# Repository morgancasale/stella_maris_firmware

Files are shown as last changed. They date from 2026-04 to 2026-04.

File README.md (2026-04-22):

# Rehabilitation Devices for One-Handed Interaction

<p align="center">
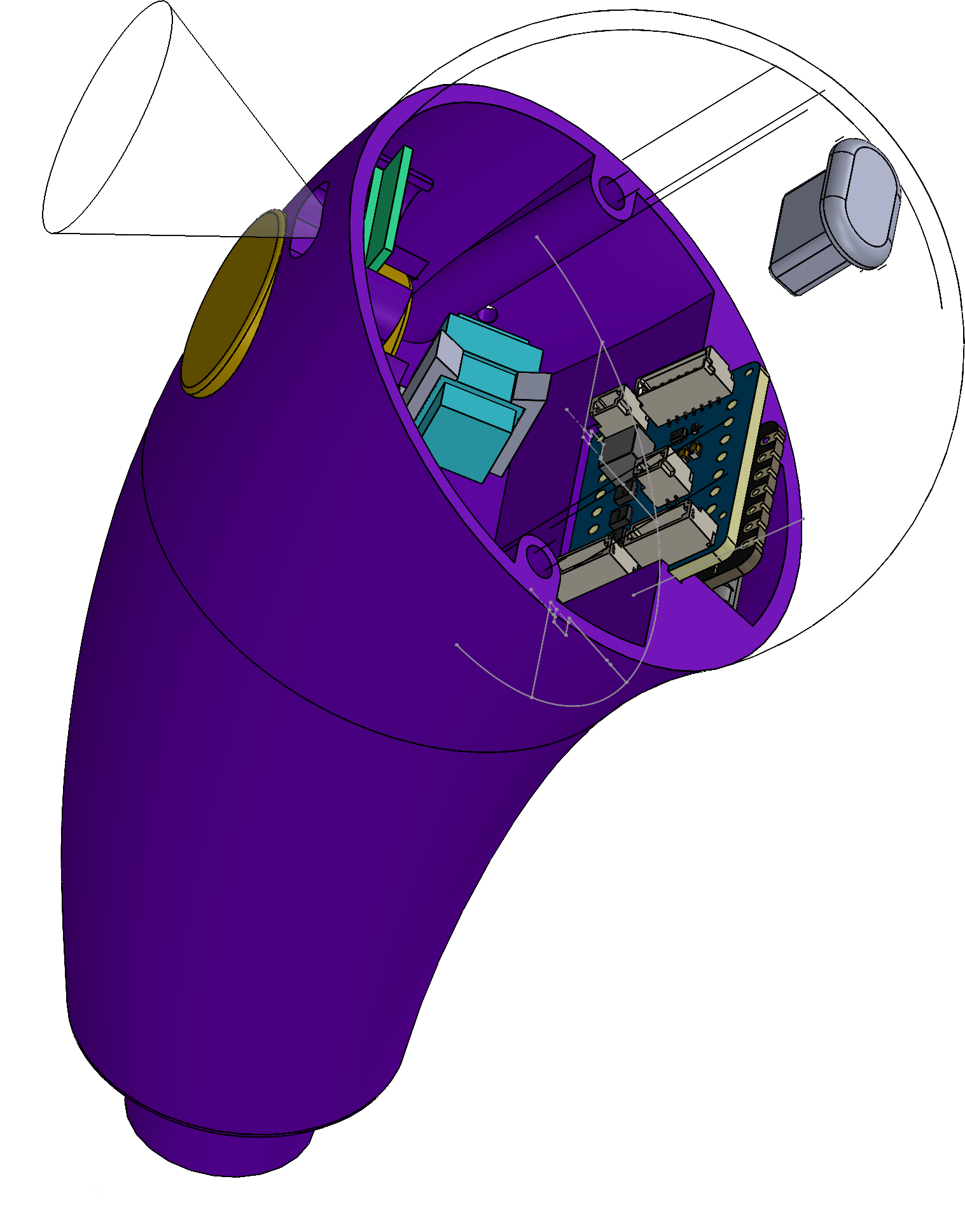
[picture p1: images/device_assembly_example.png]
     
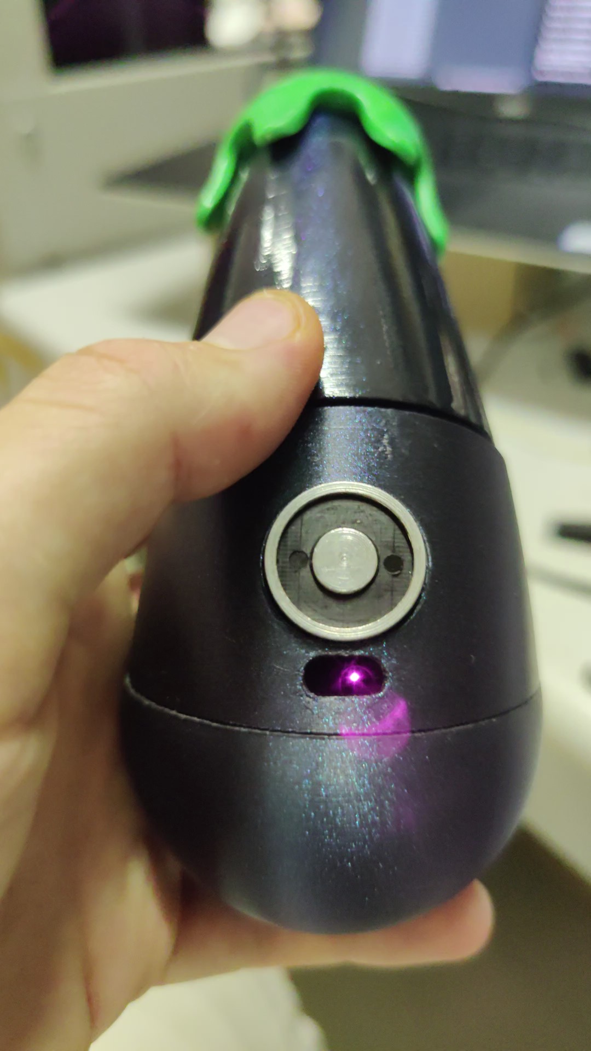
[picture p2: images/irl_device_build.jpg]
    
</p>

This project focuses on the design and development of compact rehabilitation devices intended for children who cannot use one hand. The goal is to provide engaging physical objects that help stimulate motor activity and interaction during therapy exercises.

The devices integrate sensing, actuation, and wireless communication in a very compact form factor.

---

## Project Overview

Each device contains:

- **Electromagnets** used for actuation and interaction with the patients  
- **Time-of-Flight (ToF) sensors** to detect the distance from patients  
- A **Seeed Studio XIAO ESP32-C6** microcontroller for control and wireless communication  

The devices communicate wirelessly and interact with a browser-based interface, allowing therapists or developers to monitor and control the system.

---

## Features

- Embedded firmware for **ESP32-C6**
- **Bluetooth Low Energy (BLE)** interface for communication with a JavaScript web application
- **ESP-NOW mesh-style communication** enabling multiple devices to exchange data with each other
- Integration of multiple sensors and electromagnets in a constrained physical space
- Designed for **low-power embedded operation**

---

## System Architecture

The system consists of three main layers.

### Embedded Device

Each device runs firmware on the **XIAO ESP32-C6** that:

- Reads data from ToF sensors  
- Controls electromagnets  
- Communicates with other devices using ESP-NOW  
- Exposes BLE services for external control  

### Device-to-Device Communication

Devices use **ESP-NOW** to exchange messages, enabling cooperative behaviors between multiple rehabilitation objects without requiring a central router.

### Web Interface

A **JavaScript-based interface** connects to the devices through **Bluetooth Low Energy (BLE)** to:

- Monitor device status  
- Send control commands  
- Configure behaviors  

---

## Hardware

Main components:

- **XIAO ESP32-C6**
- **Time-of-Flight (ToF) distance sensors**
- **Electromagnets**
- Custom compact enclosure designed to fit all components

The design focuses on integrating all components into a very small footprint suitable for small handheld objects.

---

## PCB Design

<p align="center">
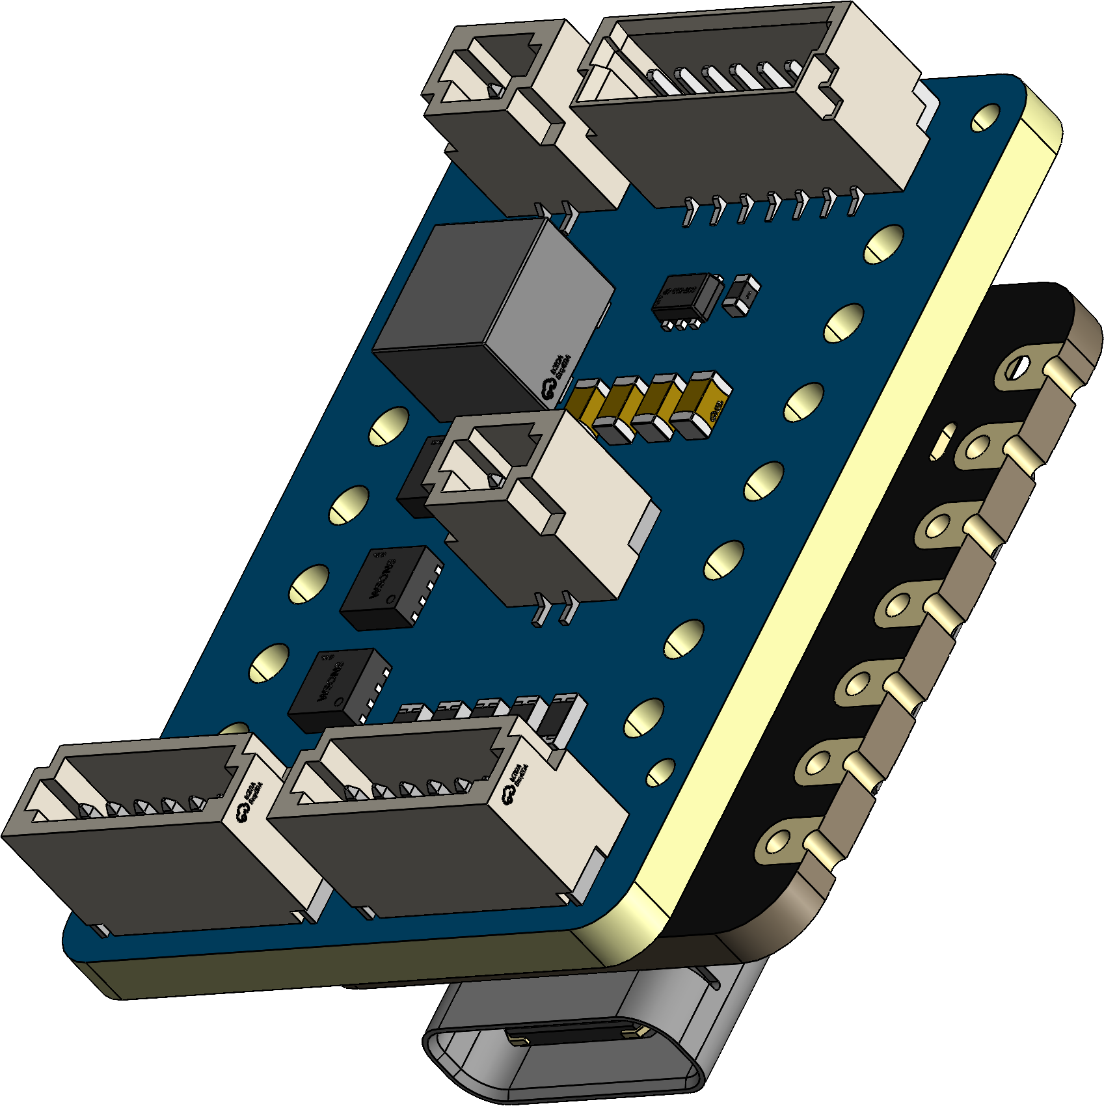
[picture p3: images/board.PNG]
    
</p> 

A custom PCB was designed to integrate all the electronic components into a compact form factor suitable for the rehabilitation devices.

<p align="center">
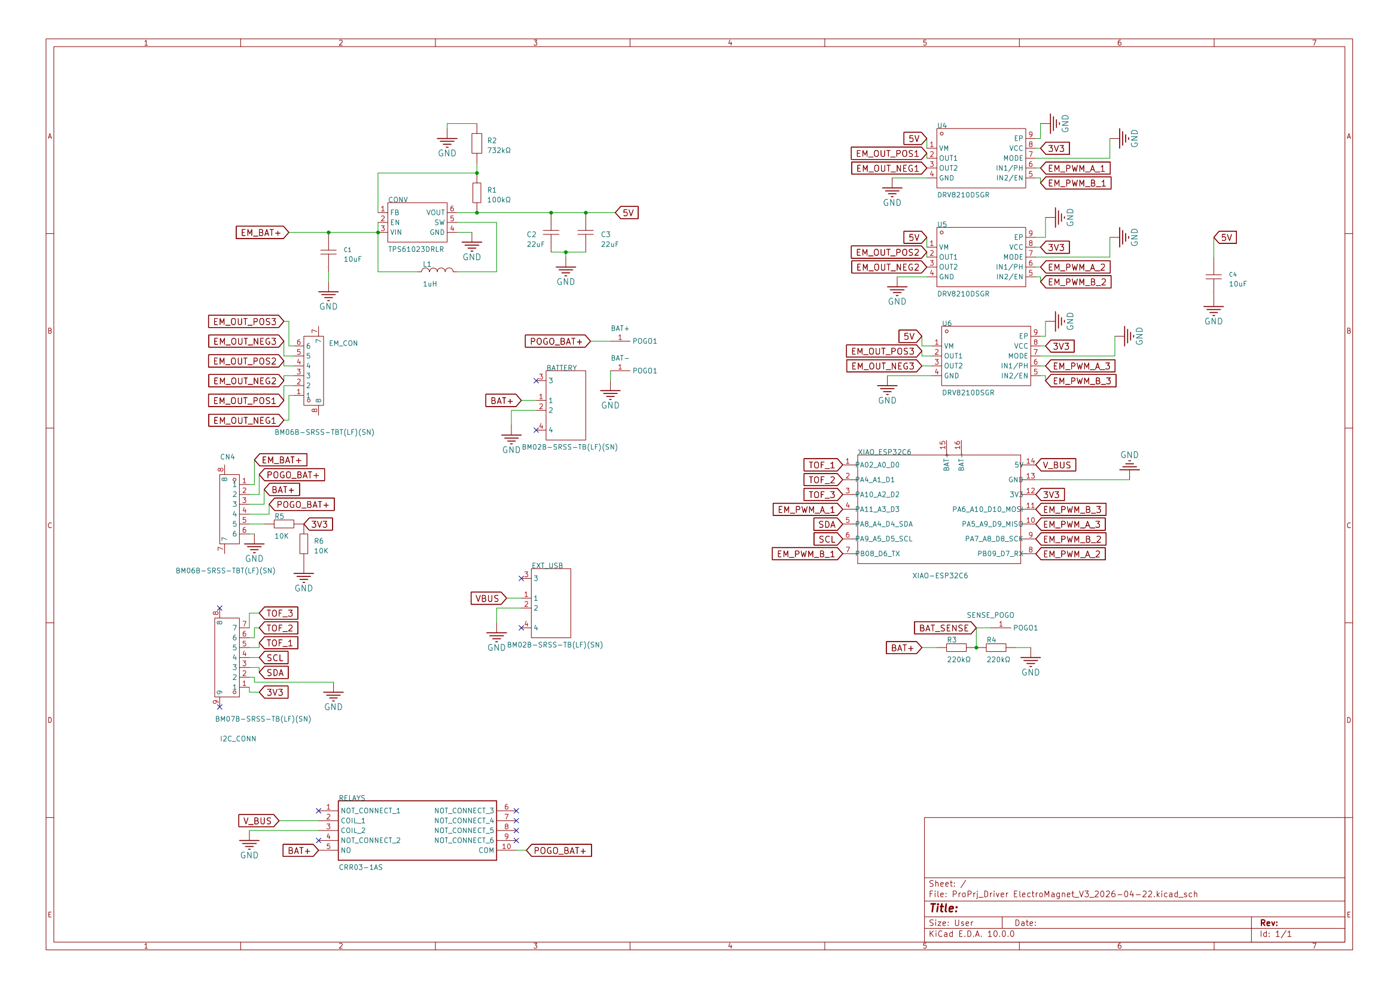
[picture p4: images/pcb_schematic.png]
    
</p>

The board includes:

- Pass through holes to solder a **Seeed Studio XIAO ESP32-C6**
- Drivers for the **electromagnets**
- Interfaces for **Time-of-Flight (ToF) sensors**
- Power management and protection circuitry
- Connectors for sensors and actuators

The PCB was designed to minimize size while keeping the system reliable and easy to assemble inside the small enclosure used by the devices.

---

## Firmware Responsibilities

The firmware handles:

- Sensor acquisition  
- Electromagnet control  
- BLE communication with the web interface  
- ESP-NOW messaging between devices  
- Resource management for a compact embedded system  

---

## Repository Structure

```
.
├── firmware/
│   └── ESP32-C6 firmware source
│
├── web-interface/
│   └── JavaScript BLE interface
│
├── hardware/
│   └── Hardware integration notes and schematics
```

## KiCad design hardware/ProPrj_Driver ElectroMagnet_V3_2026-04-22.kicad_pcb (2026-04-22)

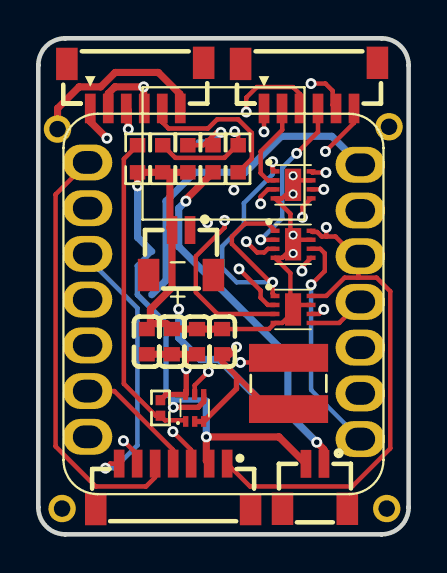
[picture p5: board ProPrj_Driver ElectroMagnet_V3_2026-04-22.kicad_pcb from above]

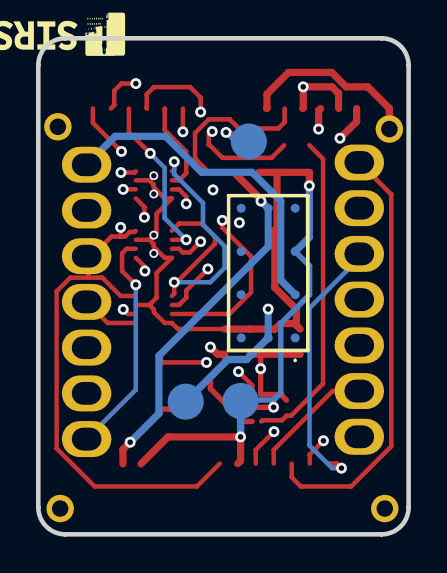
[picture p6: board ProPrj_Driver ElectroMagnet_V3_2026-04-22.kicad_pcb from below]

Board: 4 copper layers, 20.6 x 27.6 mm, 25 parts (4 on the bottom side), 28 nets.

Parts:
BAT+: pogo_pin_pad
BAT-: pogo_pin_pad
BATT: CONN-TH_BM02B-SRSS-TB-LF-SN
BUTT: CONN-SMD_BM06B-SRSS-TBT-LF-SN
C1, C2, C3, C4: C0603
CONV: SOT-563_L1.6-W1.2-P0.50-LS1.6-BR
EM: CONN-SMD_BM06B-SRSS-TBT-LF-SN
EXT_USB: CONN-TH_BM02B-SRSS-TB-LF-SN
I2C_TOF: CONN-SMD_7P-P1.00_BM07B-SRSS-TB
L1: IND-SMD_L4.1-W4.1_SPM40XX
R1: R0402
R2, R3, R4, R5, R6: R0603
RELAYS: CRR031AS
SENSE_POGO: pogo_pin_pad
U4, U5, U6: WSON-8_L2.0-W2.0-P0.50-BL-EP_DSG
XIAO_ESP32C6: MOUDLE14P-SMD-2.54-21X17.8MM

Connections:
3V3: I2C_TOF.1, R5.2, R6.2, U4.8, U5.8, U6.8, XIAO_ESP32C6.12
5V: C2.1, C3.1, C4.1, CONV.6, R1.2, U4.1, U5.1, U6.1
$1N5409: CONV.5, L1.2
$1N5536: CONV.1, R1.1, R2.2
$1N33122: BUTT.5, R5.1
BAT+: BATT.1, BUTT.3, R3.1, RELAYS.5
BAT_SENSE: R3.2, R4.1, SENSE_POGO.1
EM_BAT+: BUTT.1, C1.1, CONV.2, CONV.3, L1.1
EM_OUT_NEG1: EM.1, U4.3
EM_OUT_NEG2: EM.3, U5.3
EM_OUT_NEG3: EM.5, U6.3
EM_OUT_POS1: EM.2, U4.2
EM_OUT_POS2: EM.4, U5.2
EM_OUT_POS3: EM.6, U6.2
EM_PWM_A_1: U4.6, XIAO_ESP32C6.4
EM_PWM_A_2: U5.6, XIAO_ESP32C6.8
EM_PWM_A_3: U6.6, XIAO_ESP32C6.10
EM_PWM_B_1: U4.5, XIAO_ESP32C6.7
EM_PWM_B_2: U5.5, XIAO_ESP32C6.9
EM_PWM_B_3: U6.5, XIAO_ESP32C6.11
GND: BAT-.1, BATT.2, BUTT.6, C1.2, C2.2, C3.2, C4.2, CONV.4, EXT_USB.2, I2C_TOF.2, R2.1, R4.2, R6.1, RELAYS.3, U4.4, U4.7, U4.9, U5.4, U5.7, U5.9, U6.4, U6.7, U6.9, XIAO_ESP32C6.13
POGO_BAT+: BAT+.1, BUTT.2, BUTT.4, RELAYS.10
SCL: I2C_TOF.4, XIAO_ESP32C6.6
SDA: I2C_TOF.3, XIAO_ESP32C6.5
TOF_1: I2C_TOF.5, XIAO_ESP32C6.1
TOF_2: I2C_TOF.6, XIAO_ESP32C6.2
TOF_3: I2C_TOF.7, XIAO_ESP32C6.3
V_BUS: RELAYS.2, XIAO_ESP32C6.14

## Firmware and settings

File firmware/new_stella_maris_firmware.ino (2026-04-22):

#include "ESPNow_init.h"

#define waketime 5000

hw_timer_t *wakeTime_timer = NULL;

bool sleep_flag = false;

RTC_DATA_ATTR bool first_boot = true;
void wakeup_routine(int wake_up_pin){
  if(first_boot) {
    Serial.println("First boot!");
  } else{
    Serial.print("I'm UP! Waken by TOF "); Serial.print(wake_up_pin+1); 
    Serial.print(" on D"); Serial.print(wake_up_pin); Serial.println(".");
  }
  
  Serial.print("Waiting "); Serial.print(waketime/1000); Serial.println("s before going back to sleep...");
  //delay(waketime);
}
void IRAM_ATTR sleep_time(){
  sleep_flag = true;
}

// https://www.electronicwings.com/esp32/esp32-timer-interrupts
void setup_WakeTime_timer(){
  // Set timer frequency to 1Mhz
  wakeTime_timer = timerBegin(1000000);

  // Attach onTimer function to our timer.
  timerAttachInterrupt(wakeTime_timer, &sleep_time);

  // Set alarm time (in microseconds)
  timerAlarm(wakeTime_timer, waketime*1000, true, 0);

  Serial.println("Timer set up!");
}

bool clean_int = false;
void reset_timer(){
  bool cond = false;

  for(uint8_t TOF_pin = 0; TOF_pin<3; TOF_pin++){
    if (enabled_TOFs[TOF_pin] && digitalRead(TOF_pin)){
      cond = true;
      last_tof_in_range = TOF_pin;
    }
  }

  // if (enabled_TOFs[0]) cond |= digitalRead(WAKE_UP_PIN_0);
  // if (enabled_TOFs[1]) cond |= digitalRead(WAKE_UP_PIN_1);
  // if (enabled_TOFs[2]) cond |= digitalRead(WAKE_UP_PIN_2);

  if(cond) clean_int = true;
}

void setup() {
  uint64_t wakeup_pin = esp_sleep_get_ext1_wakeup_status() >> 1ULL;

  // https://docs.espressif.com/projects/esp-idf/en/stable/esp32/api-reference/system/sleep_modes.html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
  esp_sleep_disable_wakeup_source(ESP_SLEEP_WAKEUP_ALL); // Disable ext trigger wake for deep sleep to avoid debounce

  Serial.begin(9600);
  delay(500);
  Serial.println("Starting...");

  setup_EMs();

  setup_ESPNOW();

  setup_VL530X();

  // Setup interrupt handles for the TOF sensors to keep track if an object is still in range while awake
  for(uint8_t TOF_pin=0; TOF_pin < 3; TOF_pin++){
    if(enabled_TOFs[TOF_pin]){
      pinMode(TOF_pin, INPUT_PULLUP);
      attachInterrupt(digitalPinToInterrupt(TOF_pin), reset_timer, CHANGE); //ONLY CHANGE WORKS BOOOOH
      deactivateEM(TOF_pin);
    }
  }

  if(first_boot){
    first_boot = false;
  }

  wakeup_routine(wakeup_pin);
  
  setup_WakeTime_timer();
  clear_All_InterruptMask();
}



bool first_test = false;
void loop() {
  if (sleep_flag && EM_in_use == -1){
    // Serial.println("Sleep time?");
    sleep_flag = false;

    if (enabled_TOFs[0]) WAKE_UP_MASK |= (1ULL << WAKE_UP_PIN_0);
    if (enabled_TOFs[1]) WAKE_UP_MASK |= (1ULL << WAKE_UP_PIN_1);
    if (enabled_TOFs[2]) WAKE_UP_MASK |= (1ULL << WAKE_UP_PIN_2);

    Serial.print("Current wake_up mask: ");
    Serial.println(WAKE_UP_MASK);
    
    // https://docs.espressif.com/projects/esp-idf/en/release-v4.4/esp32/api-reference/system/sleep_modes.html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
    esp_sleep_enable_ext1_wakeup(WAKE_UP_MASK, ESP_EXT1_WAKEUP_ANY_HIGH);
        
    clear_All_InterruptMask();
    delay(1000);

    Serial.println("Going back to sleep...");
    esp_deep_sleep_start();
  } else {
    sleep_flag = false;
  }

  // If object still in range the sleep timer is reset and the device doesn't go to sleep
  if(clean_int || EM_in_use != -1){
    if(clean_int){
      Serial.print("Object still in range of");
      for(uint8_t TOF_pin=0; TOF_pin < 3; TOF_pin++){
        if(enabled_TOFs[TOF_pin] && digitalRead(TOF_pin)){
          Serial.print(" TOF "); Serial.print(TOF_pin);
        }
      }
      Serial.println("!");
      
      Serial.print("Last TOF in range: "); Serial.println(last_tof_in_range);
      clean_int = false;
    }

    if(EM_in_use != -1){
      Serial.print("EM"); Serial.print(EM_in_use);
      Serial.println(" is still in use! Can't go to sleep...");
    }

    clear_All_InterruptMask();
    
    timerRestart(wakeTime_timer);
    delay(50);
  }

  
  
  delay(10);
}

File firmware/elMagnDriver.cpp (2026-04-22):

#include "elMagnDriver.h"

// Initialize motor shield and IMU
//DRV8835MotorShield motors(0, 1, 7, 8);
//LSM6DS3 myIMU(I2C_MODE, 0x6A);

// Mode and state variables
int deviceMode = MODE_MANUAL;
bool EMStates[3] = {ELECTROMAGNET_OFF, ELECTROMAGNET_OFF, ELECTROMAGNET_OFF};
int EM_in_use = 3; //Until setup_EMs() isn't called the Electromagnets will not work 
int amplitude = 100;


void setup_EMs(){
  for(uint8_t i=0; i < 3; i++){
    pinMode(positive_pins[i], OUTPUT);
    analogWrite(positive_pins[i], 0);
    delay(10);
    pinMode(negative_pins[i], OUTPUT);
    analogWrite(negative_pins[i], 0);
    delay(20);
  }
  EM_in_use = -1;
  Serial.print("EM value: "); Serial.println(EM_in_use);
}

void activateEM(uint8_t EM_num){
  if(EM_num < 0 || EM_num > 2) return;

  if(EM_in_use != -1 && EM_in_use != EM_num){
    Serial.println("An EM is already in use!");
    return;
  }

  if (!EMStates[EM_num] && enabled_TOFs[EM_num]){
    EM_in_use = EM_num;

    analogWrite(negative_pins[EM_num], 0);
    analogWrite(positive_pins[EM_num], EM_POWER);
    
    EMStates[EM_num] = ELECTROMAGNET_ON;
    Serial.print("Electromagnet "); Serial.print(EM_num); Serial.println(" is ON!");
  }
}

void deactivateEM(uint8_t EM_num){
  if(EM_num < 0 || EM_num > 2) return;

  if(EM_in_use != -1 && EM_in_use != EM_num){
    Serial.println("An EM is already in use!");
    return;
  }

  if (EMStates[EM_num] && enabled_TOFs[EM_num]){
    // First put positive current to 0
    analogWrite(positive_pins[EM_num], 0);
    // Then pass negative current for some time 
    analogWrite(negative_pins[EM_num], EM_BACK_CURRENT_POWER);
    delay(EM_BACK_CURRENT_DELAY);

    // Finally set negative current also back to 0
    analogWrite(negative_pins[EM_num], 0);

    EMStates[EM_num] = ELECTROMAGNET_OFF;

    EM_in_use = -1;

    Serial.println("Electromagnet OFF");
  }
}


void toggleEM(uint8_t EM_num){
  if(EM_num < 0 || EM_num > 2) return;

  if(EM_in_use != -1 && EM_in_use != EM_num){
    Serial.println("An EM is already in use!");
    return;
  }

  if (!EMStates[EM_num] && enabled_TOFs[EM_num]){
    activateEM(EM_num);
  } else if(enabled_TOFs[EM_num]){
    deactivateEM(EM_num);
  }
}

// void ElMagnetAutoControl(){
//   float normAccel = sqrt(
//     myIMU.readFloatAccelX() * myIMU.readFloatAccelX() +
//     myIMU.readFloatAccelY() * myIMU.readFloatAccelY() +
//     myIMU.readFloatAccelZ() * myIMU.readFloatAccelZ()
//   );

//   //Serial.print("Message = ");
//   //Serial.println(normAccel);
//   if (electromagnetState == true){
//     if (normAccel > 1.08) {
//       lastMoveTime = millis();
//     }else if (millis() - lastMoveTime > 1000) {
//       deactivateElectromagnet();
//       delay(500);
//     }

//   }else{
//     if (normAccel > 1.04) {
//       activateElectromagnet(amplitude);
//       Serial.println(normAccel);
//       Serial.println(amplitude);
//       lastMoveTime = millis();
//     }
//   }
// }

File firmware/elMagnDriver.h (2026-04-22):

#ifndef elMagnDriver_h
#define elMagnDriver_h
  //#include <DRV8835MotorShield.h>
  // #include <Arduino_LSM6DS3.h>
  #include <Arduino.h>
  #include "VL53L0X_init.h"

  // Constants for operating modes and electromagnet state
  #define MODE_MANUAL 1
  #define MODE_AUTO 2
  #define ELECTROMAGNET_ON true
  #define ELECTROMAGNET_OFF false

  #define EM_POWER 255
  #define EM_BACK_CURRENT_POWER 255
  #define EM_BACK_CURRENT_DELAY 200
  #define POSITIVE_PIN D0
  #define NEGATIVE_PIN D1

  const uint8_t positive_pins[3] = {D6, D8, D10};
  const uint8_t negative_pins[3] = {D3, D7, D9};

  //extern DRV8835MotorShield motors;
  //extern LSM6DS3 myIMU;

  // Mode and state variables
  extern int deviceMode;
  extern bool EMStates[3];
  extern int EM_in_use;
  extern int amplitude;

  void setup_EMs();

  void activateEM(uint8_t EM_num);
  void deactivateEM(uint8_t EM_num);
  void toggleEM(uint8_t EM_num);

  extern void ElMagnetAutoControl();

#endif

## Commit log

2024-12-10 Arduino libraries fix
2024-12-10 Controller button fix with electromagnets
2024-12-30 Added BLE characteristic to update interface of device's electromagnet state
2026-04-22 adding things
    [ProPrj_Driver ElectroMagnet_V3_2026-04-22.kicad_pcb, ProPrj_Driver ElectroMagnet_V3_2026-04-22.kicad_sch]
2026-04-22 Modified readme
    [ProPrj_Driver ElectroMagnet_V3_2026-04-22.kicad_sch]
